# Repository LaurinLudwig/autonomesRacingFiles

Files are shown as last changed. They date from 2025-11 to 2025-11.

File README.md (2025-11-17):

# Projektübersicht & Nützliche Links

Dieses Repository enthält alle relevanten Unterlagen, Diagramme und Dateien rund um die Entwicklung unserer mobilen Roboterplattform und der zugehörigen Software-/Systemarchitektur.

## Inhalt des Repositories

- **CAD/**  
  enthält .Step und .3MF Dateien zum Drucken von Ersatzteilen

- **ChangedRosFiles/**  
  angepasste ROS-Dateien für unsere Plattform

- **Finanzplan_Antrag_Roboter_plattformen.xlsx**  
  Auflistung der verwendeten/bestellten Komponenten

- **KabelDiagramme.pdf / KabelDiagramme.pptx**  
  Übersicht der Verkabelung, Schnittstellen und elektrischen Verbindungen

- **SystemDiagramme.pdf / SystemDiagramme.pptx**  
  Schaubild der Komponenten

- **ReadmeAndUsefulLinks.md**  
  (Diese Datei) Kurze Einführung in das Repo und Sammlung relevanter Ressourcen.

## Useful Links

### Allgemein & Inspiration
- **Roboracer.ai**  
  https://roboracer.ai/

### Hardware / Jetson Setup
- **reComputer J4012 – JetPack Flash Guide**  
  https://wiki.seeedstudio.com/reComputer_J4012_Flash_Jetpack/

### Software / ROS 2
- **ROS 2 Humble Dokumentation**  
  https://docs.ros.org/en/humble/index.html

### F1TENTH / Driverless-Ökosystem
- **F1TENTH System Repository (humble-devel)**  
  *Hinweis: läuft nicht out-of-the-box; stattdessen Thomas Wiemanns Fork verwenden*  
  https://github.com/f1tenth/f1tenth_system/tree/humble-devel

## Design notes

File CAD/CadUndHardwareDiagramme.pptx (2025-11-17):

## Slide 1

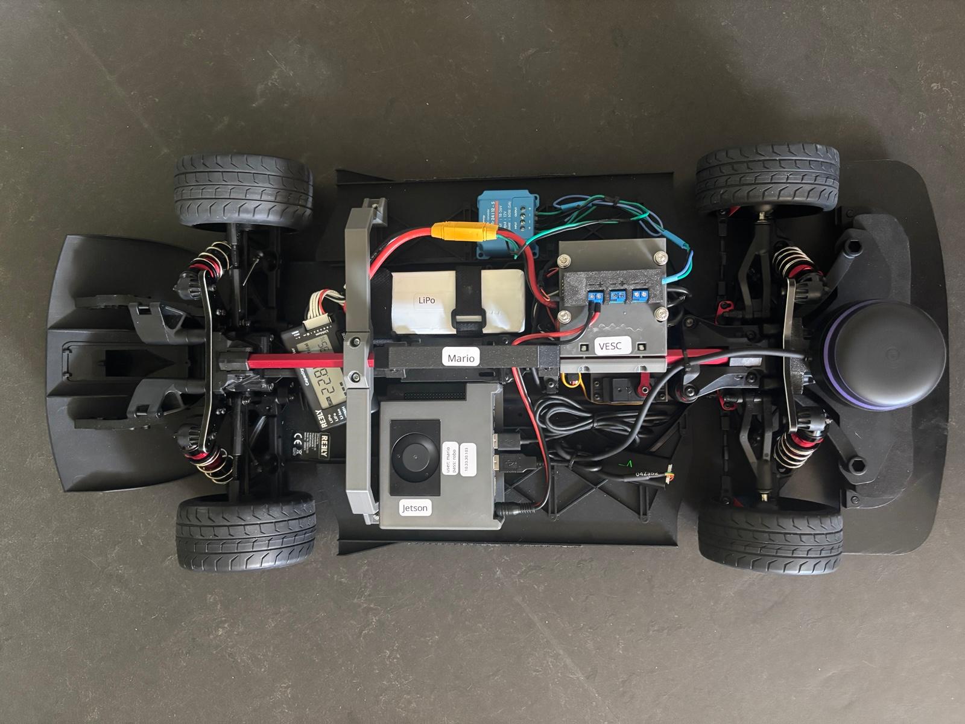
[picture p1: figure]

powerDistributionCover
(Lochrasterplatte, Terminals, 90 Grad Header Pins)

Handle + 2x HandleClamp
(4x M3, 4x M3 self locking Nut)

VescMount +
VescMountClamp
(4x M5, 4x M3,
4x M3 self locking Nut)

Enforcer Bracket +
EnforderBracketClamp
(4x M3, 4x M3 self locking Nut)

RPLidarMount
(2x M5, 4x M3)

JetsonCase +
JetsonCaseBottom
(4x M3)

ServoMount
(2x M4, 4x M3)

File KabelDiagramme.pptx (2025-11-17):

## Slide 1

DC 24V

DCDC 5V

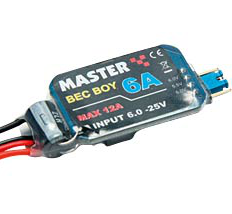
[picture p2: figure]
AKKU-BEC für RC-Empfänger, 6 A

DC 5V

Wifi Router

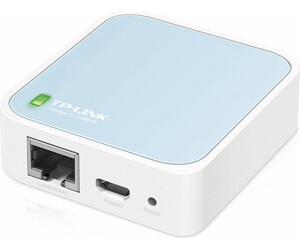
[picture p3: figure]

Ethernet

USB
DC 5V

optional DC 5V

RPLidar A3M1

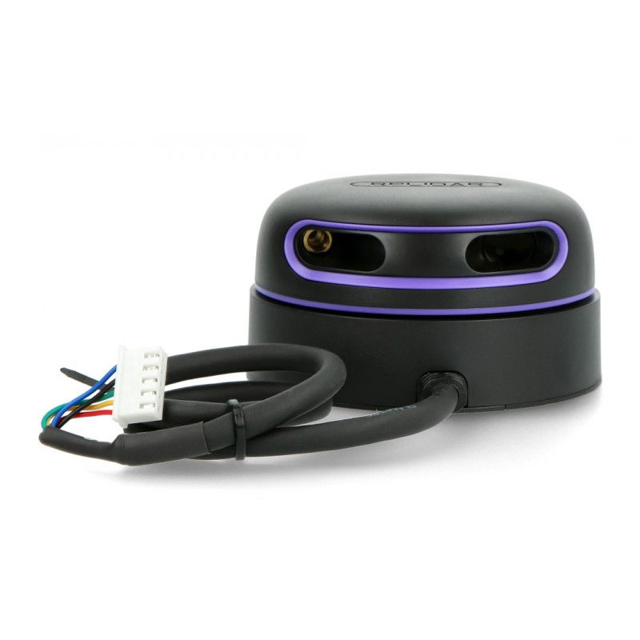
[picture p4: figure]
RPLidar A3M1 Laserscanner - 360 Grad - 25m

LiPo

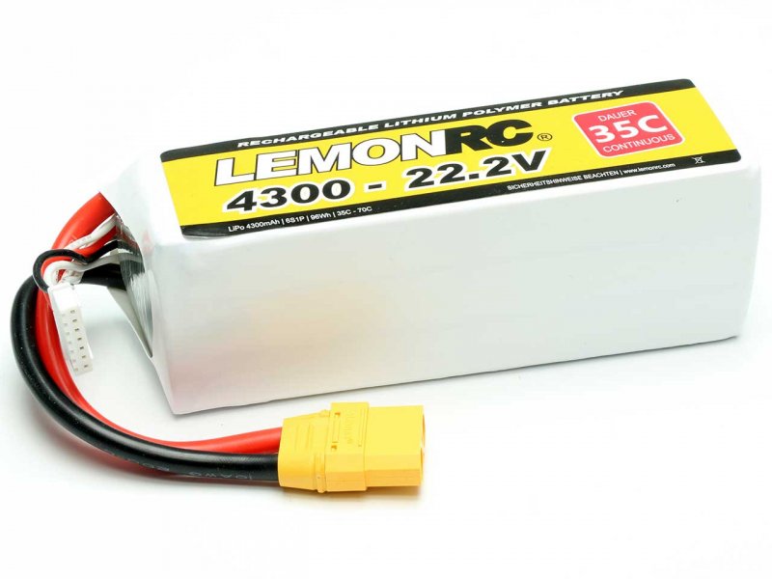
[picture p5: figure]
LiPo Akku LEMONRC 4300 - 22.2V (35C), 99,95 €

DC 24V

DC 24V

DCDC 12V

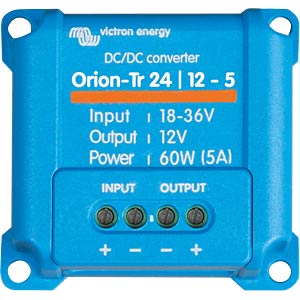
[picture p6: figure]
DC/DC Konverter, 12,7 V, 5 A

DC 12V

Nvidia Jetson Orin

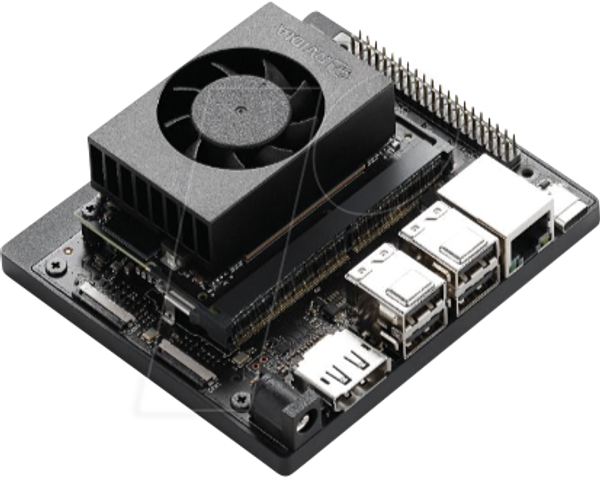
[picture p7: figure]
NVIDIA NVIDIA Jetson Orin Nano Super Dev. Kit, 67 TOPS, 8 GB DDR5 | Bundles / Sets / Kits günstig kaufen | reichelt elektronik

USB-UART
(Motor und Servo)

VESC 6

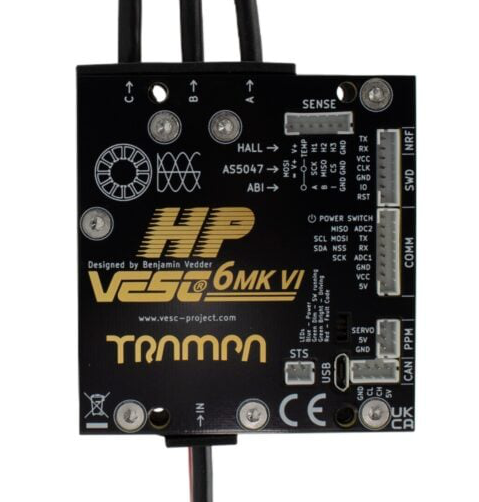
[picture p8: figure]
VESC 6 Mk6 HP - Trampa - The world leading brand of Electric Mountainboards

USB-UART
(Lidardaten)

Balancing Stecker
(Spannungsanzeige/
Unterspannungsschutz)

DC 24V

LiPo Checker

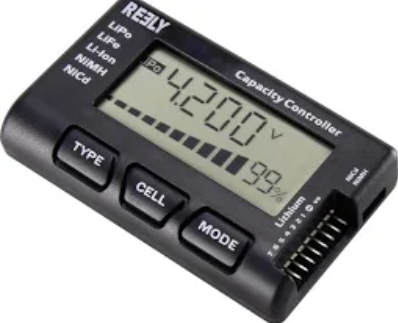
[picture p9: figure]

PWM-Output

Servo Motor

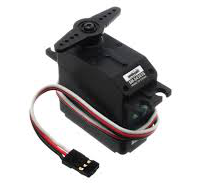
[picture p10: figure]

BLDC-Motor

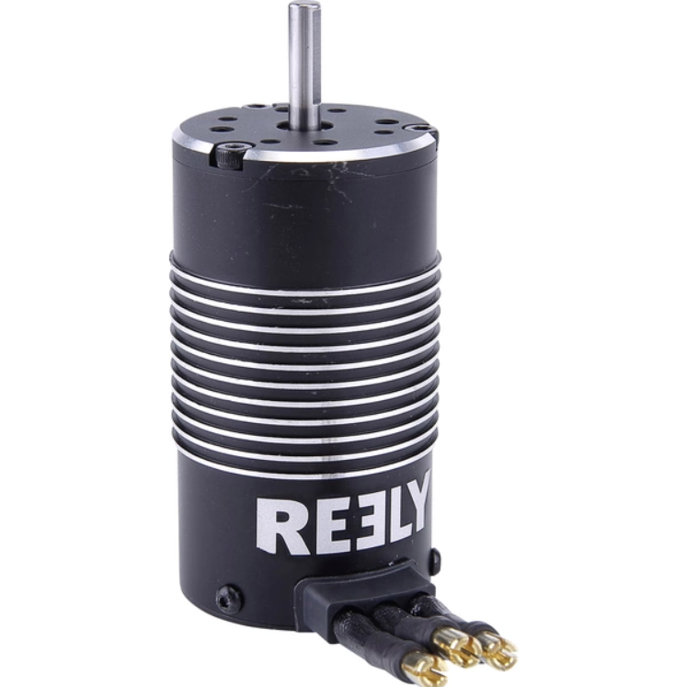
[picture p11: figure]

3 Motorphasen

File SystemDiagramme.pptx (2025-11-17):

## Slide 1


DCDC-Wandler
(24V-12V, 24V-5V)

Spannungsverteiler (12V, 5V)

Motorcontroller (VESC 6)

LiPo
(6S 4300mAH)

Motor
(BLDC 2000kV 3800W)

LiPo-Checker

Lidar (RPLidar A3M1)

Computer
(Jetson Orin NX,
8x 2 GHz, 16 GB DDR5)

Lenkmotor
(Standard Servo)

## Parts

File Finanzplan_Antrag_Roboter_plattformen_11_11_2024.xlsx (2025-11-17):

vorläufiger Finanzplan Antrag: Testplattformen für Autonomes Fahren
Stück | Artikel | Information | Preis | Gesamt | Link |  | Preis Gesamt für eine beginner und eine fortgeschrittene Plattform
 |  |  |  |  |  |  | 6750€ | (Alle Preise mit Steuern für End-User)
2 | NVIDIA Jetson Orin NX Bundle |  | 705 € | 1410 | https://www.reichelt.com/ch/de/shop/produkt/nvidia_jetson_orin_nx_bundle_8x_2_ghz_16_gb_ddr5-377868
2 | TIM361-2134101 | Preis auf Anfrage | 1550 € | 3100 | https://www.sick.com/de/de/produkte/lidar-und-radarsensoren/lidar-sensoren/tim/tim361-2134101/p/p369447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
 |  |  |  |  |  |  | Preis Gesamt für beantragte Summe für jeweils zwei Plattformen
2 | ODrive S1 and M8325s |  | 329 € | 658 | https://odriverobotics.com/shop/s1-and-m8325s-start-kit |  | 13500
2 | 1/7 RC Wheels |  | 40 € | 80 | https://www.conrad.de/de/p/reely-re-7867935-ersatzteil-komplettraeder-hinten-2622645.html
6 | Harness Build Kit For ODrive S1 |  | 9 € | 54 | https://odriverobotics.com/shop/harness-build-kit-for-odrive-s1
2 | Standard Servo |  | 25 € | 50 | https://www.reichelt.com/it/de/shop/produkt/standardservo_13_kg_digital_metallgetriebe-280644
1 | Servo Tester |  | 10 € | 10 | https://www.reichelt.com/it/de/shop/produkt/servotester_fuer_3_servos_ccpm_mini-119122
 |  |  |  | 0
2 | DYNAMIXEL AX-12A Servomotor | Alternative für Standard Servo, Comm. Over Uart | 60 € | 120 | https://www.reichelt.com/it/de/shop/produkt/servomotor_robotik_9_0_-_12_v_dc-249909
1 | 1/7 RC Auto Plattform |  | 350 € | 350 | https://www.conrad.de/de/p/reely-urban-green-brushless-1-7-rc-modellauto-elektro-strassenmodell-allradantrieb-4wd-rtr-2-4-ghz-mit-lichteffekt-t-2586837.html
1 | ODrive S1 | Foc BLDC Motor Driver for 1/7 Car | 149 € | 149 | https://eu.odriverobotics.com/shop/odrive-s1
1 | Odrive S1 Case |  | 19 € | 19 | https://eu.odriverobotics.com/shop/enclosure-for-odrive-s1
1 | Mono IMX219-160 |  | 25 € | 25 | https://www.conrad.de/de/p/waveshare-imx219-160-ir-kamera-8mp-160-fov-infrarot-ai-gesichtserkennung-jetson-nano-xavier-nx-906009355.html
1 | Stereo IMX219-83 |  | 45 € | 45 | https://www.conrad.de/de/p/stereo-kamera-modul-imx219-83-8-megapixel-838242168.html
1 | Akku Ladegerät |  | 45 € | 45 | https://www.reichelt.com/it/de/shop/produkt/ladegeraet_fuer_akkupacks_fuer_1-6s_max_6_a-271070
2 | 24v Lipo Akku |  | 85 € | 170 | https://www.reichelt.com/it/de/shop/produkt/lipo_akku_lemonrc_3300_-_22_2v_35c_-385712
1 | 5v Regler mit Abschaltung |  | 9.50 € | 9.5 | https://www.conrad.de/de/p/hobbywing-bec-3a-ubec-bec-spannungsregler-5-5-26-v-2108347.html
1 | Step up/down wandler für jetson |  | 50 € | 50
1 | Verschiedenes |  | 405.5 € | 405.5
Update 11.11.2024
Anz | Artikel | ohne MwSt | mit | ges | Link
4 | NVIDIA Jetson Orin NX Bundle |  | 996.8 | 3987.2 | JET ORIN 4012: NVIDIA Jetson Orin NX Bundle, 8x 2 GHz, 16 GB DDR5 bei reichelt kaufen (https://www.reichelt.com/de/de/shop/produkt/nvidia_jetson_orin_nx_bundle_8x_2_ghz_16_gb_ddr5-377868) | gibt’s nur da
4 | RPLIDAR A3M1 360° LiDAR (25m) |  | 706.6 | 2826.4 | https://www.reichelt.de/rplidar-a3m1-360-lidar-25m--rplidar-a3m1-p287745.html?&trstct=vrt_pdn&nbc=1 | Angebot | Alternative | Anz | Artikel | ohne | mit | ges
5 | VESC 6MkVI | 195 | 232.05 | 1160.25 | The Amazing TRAMPA VESC 6 MkVI gives Maximum power! (https://trampaboards.com/vesc-6-mkvi--trampa-gives-you-maximum-power-p-34848.html) | gibt’s nur da |  | 4 | ODrive S1 | 149 | 177.31 | 709.24 | ODrive S1 — ODrive Europe (https://eu.odriverobotics.com/shop/odrive-s1)
8 | vesc 6 ppm cable for servo | 2.5 | 2.975 | 23.8 | https://trampaboards.com/maytech-to-vesc-150mm-ppm-extension-cable--silicon-cable-24-awg-blackredwhite-p-24329.html |  |  | 4 | Odrive S1 Case | 19 | 22.61 | 90.44 | Enclosure for ODrive S1 — ODrive Europe (https://eu.odriverobotics.com/shop/enclosure-for-odrive-s1)
4 | Raspberry Pi - Kamera, 5MP, 160° |  | 12.08 | 48.32 | RPI WWCAM: Raspberry Pi - Kamera, 5MP, 160° bei reichelt elektronik (https://www.reichelt.de/raspberry-pi-kamera-5mp-160--rpi-wwcam-p148944.html?PROVID=2788&gad_source=1) |  |  | 4 | Odrive USB-CAN Adapter | 39 | 46.41 | 185.64 | USB-CAN Adapter — ODrive Europe (https://eu.odriverobotics.com/shop/usb-can-adapter)
4 | 1/7 RC Auto Plattform |  | 335.29 € | 1341.16 | Reely Urban Green Brushless 1:7 RC Modellauto Elektro Straßenmodell Allradantrieb (4WD) RtR 2,4 GHz mit Lichteffekt, T kaufen (https://www.conrad.de/de/p/reely-urban-green-brushless-1-7-rc-modellauto-elektro-strassenmodell-allradantrieb-4wd-rtr-2-4-ghz-mit-lichteffekt-t-2586837.html) | Angebot
4 | Akku Ladegerät IMAX B6AC V2 |  | 71.95 | 287.8 | IMAX B6AC V2: Ladegerät für Akkupacks, für 1 - 15 Zellen, max. 6 A, USB bei reichelt elektronik (https://www.reichelt.de/ladegeraet-fuer-akkupacks-fuer-1-15-zellen-max-6-a-usb-imax-b6ac-v2-p182805.html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)
8 | 24v 6s 4300mah Lipo Akku |  | 99.95 | 799.6 | https://www.conrad.de/de/p/lemonrc-modellbau-akkupack-lipo-22-2-v-4300-mah-zellen-zahl-6-35-c-softcase-xt90-2867021.html | Screenshots
4 | 5v Regler mit Abschaltung |  | 29.4 | 117.6 | MASTER C6354: AKKU-BEC für RC-Empfänger, 6 A bei reichelt elektronik (https://www.reichelt.de/akku-bec-fuer-rc-empfaenger-6-a-master-c6354-p265511.html?search=bec)
4 | 24-12V wandler VE TR 24/12-5 |  | 15.47 | 61.88 | VE TR 24 - 12-5: DC - DC Konverter, 12,7 V, 5 A bei reichelt elektronik (https://www.reichelt.de/dc-dc-konverter-12-7-v-5-a-ve-tr-24-12-5-p300230.html?PROVID=2788&gad_source=1)
4 | Relais GRV RELAY SPDT30 |  | 11.2 | 44.8 | GRV RELAY SPDT30: Arduino - Relais SPDT, 30 A, SLA-05VDC-SL-C bei reichelt elektronik (https://www.reichelt.de/arduino-relais-spdt-30-a-sla-05vdc-sl-c-grv-relay-spdt30-p243033.html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)
2 | Lipo Tasche EXTRON X3363 |  | 34.2 | 68.4 | EXTRON X3363: Lithium Tresor, inkl. Fireballs 3x 1L bei reichelt elektronik (https://www.reichelt.de/lithium-tresor-inkl-fireballs-3x-1l-extron-x3363-p253651.html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)
1 | 2,5mm2 Kabel |  | 15 | 15 | GOOBAY 15099: Lautsprecherkabel 2x2,5mm² , 10 m rot/schwarz CU bei reichelt kaufen (https://www.reichelt.com/ch/de/shop/produkt/lautsprecherkabel_2x2_5mm_10_m_rot_schwarz_cu-364183)
4 | LiPo-Checker |  | 17.99 | 71.96 | https://www.conrad.de/de/p/reely-lipo-checker-geeignet-fuer-batterie-zellen-2-7-1-st-re-6546762-2182254.html
 |  |  | Summe | 10854.17

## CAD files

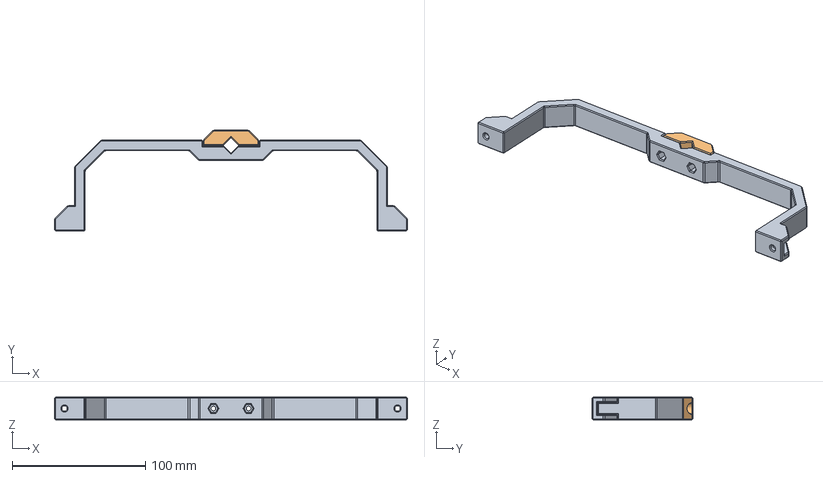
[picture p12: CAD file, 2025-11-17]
CAD/EnforcingBracket/SideplateEnforcingBracket.step
265.0 x 75.7 x 17.0 mm

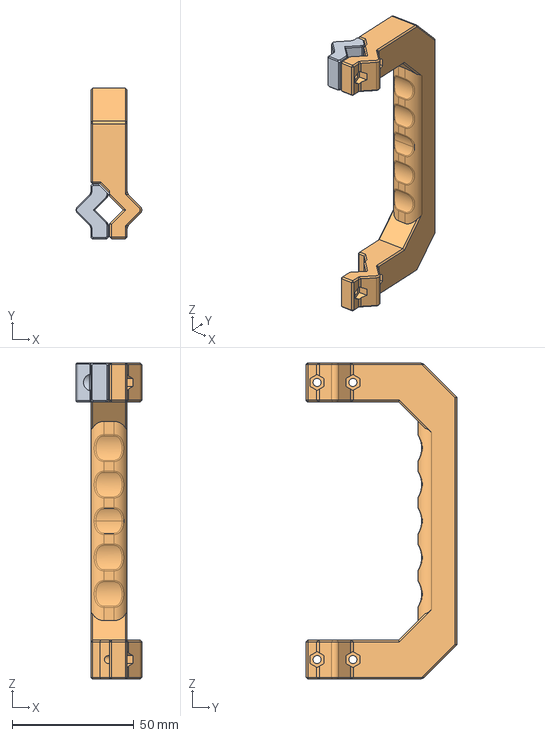
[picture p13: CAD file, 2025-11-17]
CAD/Handle/handle.step
27.0 x 62.0 x 130.0 mm

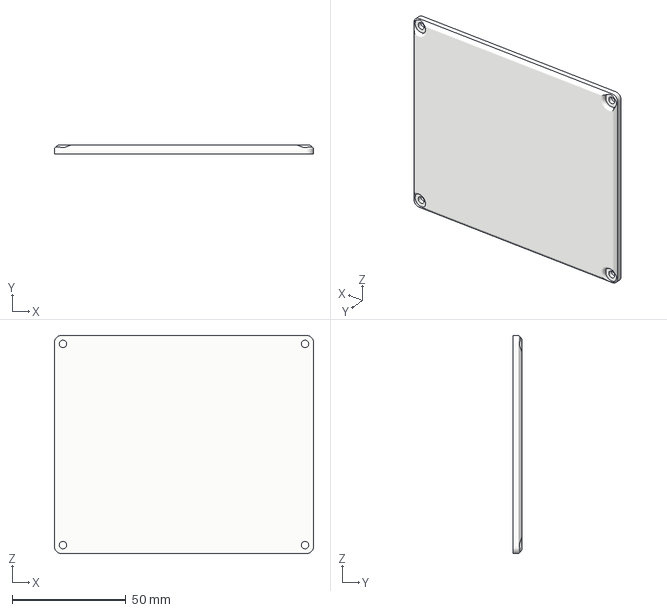
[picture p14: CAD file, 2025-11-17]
CAD/JetsonCase/case_m3_self_tapping/Lid.3mf
114.0 x 4.00 x 96.0 mm

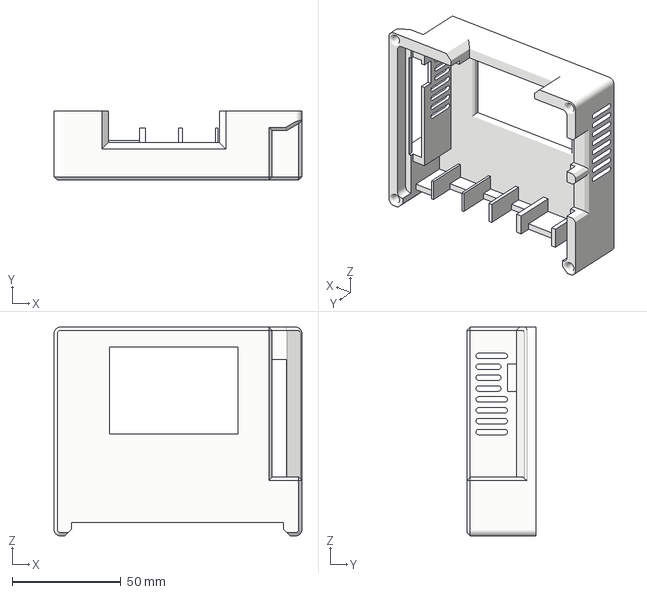
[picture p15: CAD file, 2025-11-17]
CAD/JetsonCase/case_with_m3_inserts/JetsonCaseM3Inserts.3mf
114.0 x 31.8 x 96.0 mm

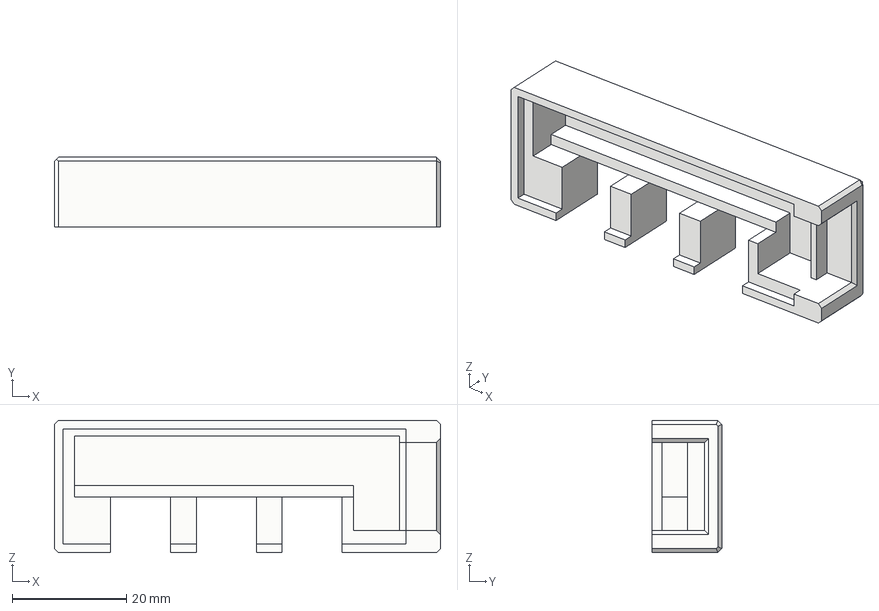
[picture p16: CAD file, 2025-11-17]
CAD/powerDistributionCover/PowerDistriCover.step
67.5 x 12.2 x 23.1 mm

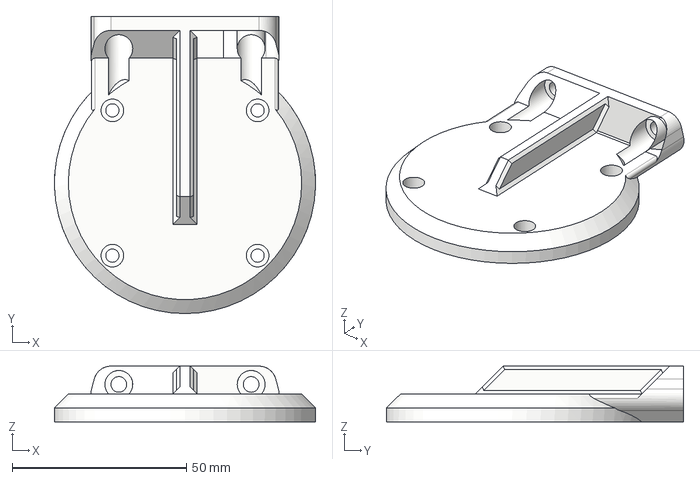
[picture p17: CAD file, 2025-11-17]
CAD/RPLidarMount/mounting_position_high/RPLidar_Mount_high.step
75.0 x 85.4 x 16.0 mm

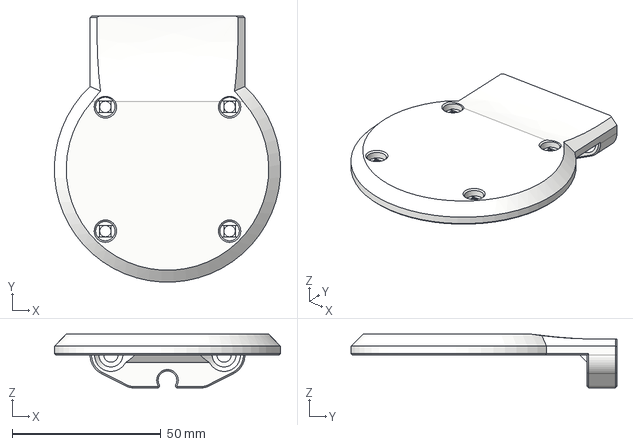
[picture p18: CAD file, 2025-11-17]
CAD/RPLidarMount/mounting_position_low/RPLidar_Mount_low.step
75.9 x 89.3 x 18.0 mm

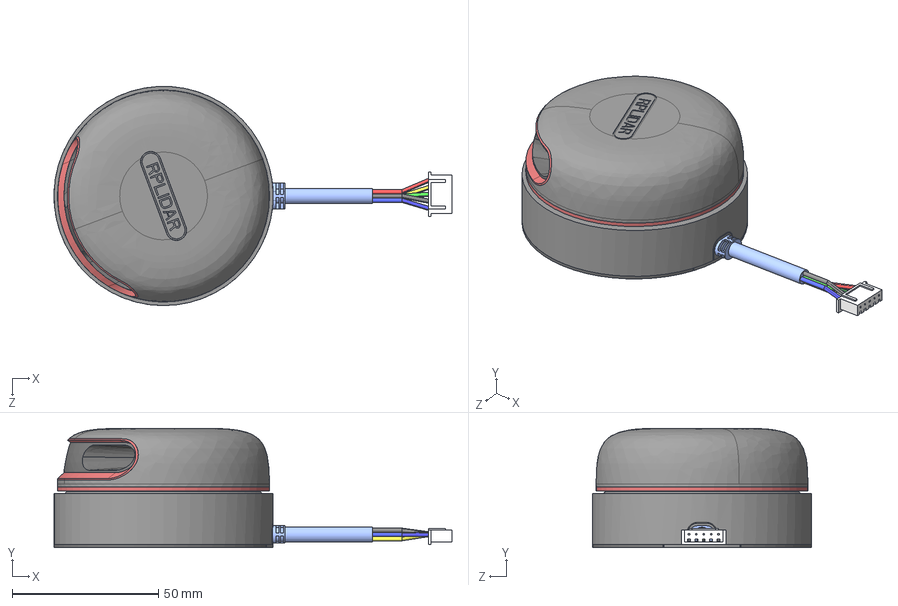
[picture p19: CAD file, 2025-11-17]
CAD/RPLidarMount/rplidar-a2m4-r1.step
136.2 x 40.8 x 75.0 mm
µ×¸Ç
4pinÏßÀÂ
½ÓÏß¶Ë¸Ç
6p ²åÍ·
Áã¼þ4^Íâ½ÓÏßÕ ûÌå
5pin 2.54²åÍ·
Áã¼þ1^Íâ½ÓÏßÕ ûÌå
±àÂë³ÝÍâ¿Ç
Ðý×ªÆ½Ì¨
LENS_1.6
KEY_1.6
BAT_COVER_19
·â¸Ç
¼¤¹â·¢ÉäÍ·
¾µÍ·

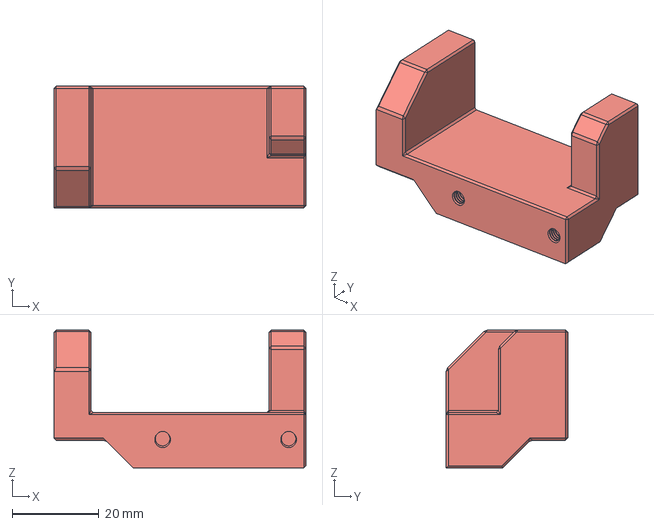
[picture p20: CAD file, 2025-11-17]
CAD/ServoMount/ServoMount.step
58.0 x 28.0 x 31.8 mm

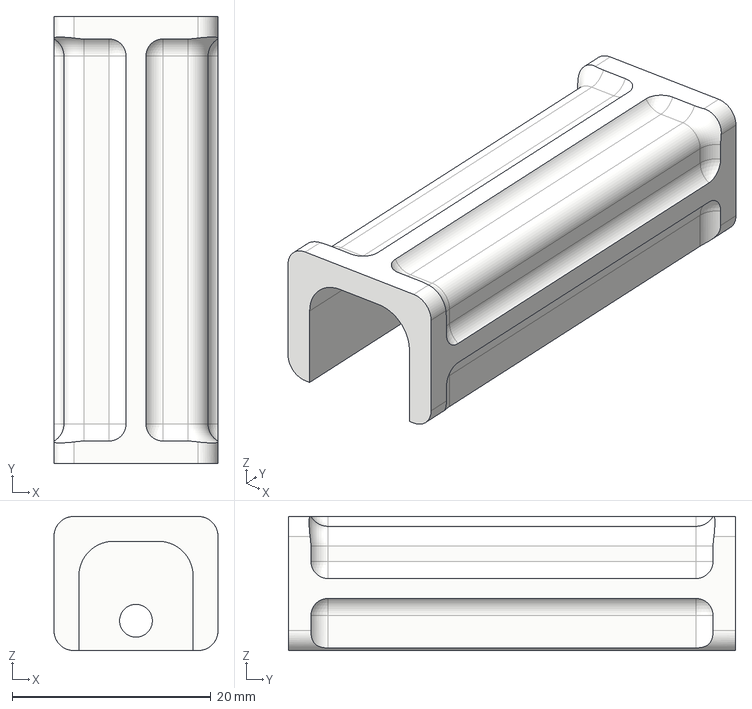
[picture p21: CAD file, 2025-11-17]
CAD/SprocketCover/SprocketCover.step
16.5 x 45.0 x 13.5 mm

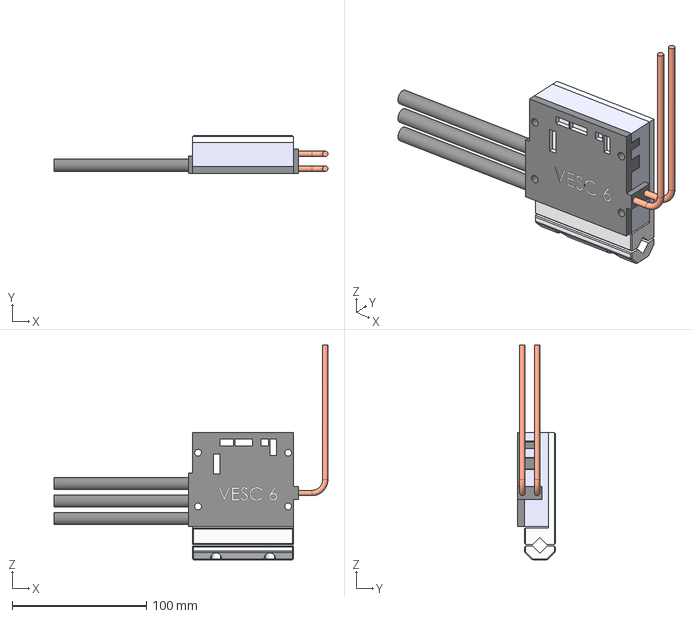
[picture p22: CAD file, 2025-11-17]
CAD/VescMount/VescMount.step
203.8 x 28.0 x 159.7 mm
VESC6HeatSink
VESC6Top

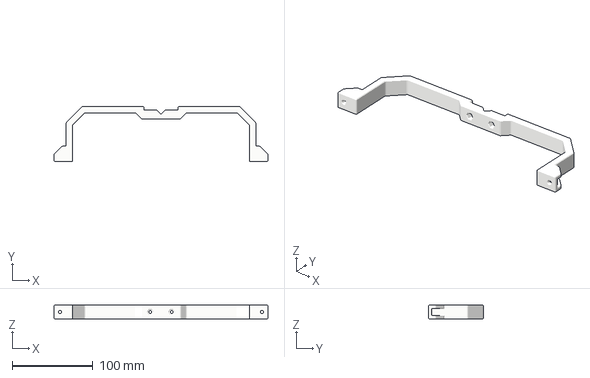
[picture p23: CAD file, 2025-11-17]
CAD/EnforcingBracket/EnforcingBracket.3mf
265.0 x 68.2 x 17.0 mm

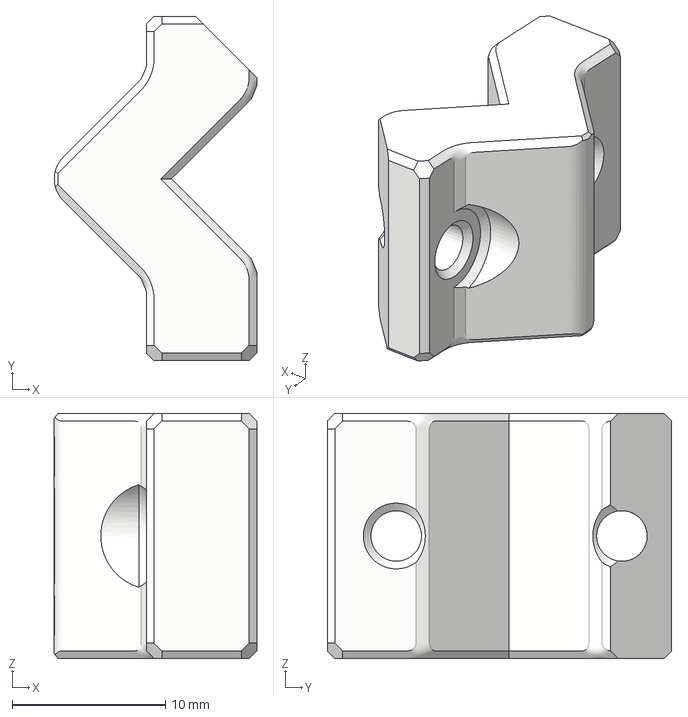
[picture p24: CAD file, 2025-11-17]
CAD/Handle/handle_clamp.3mf
13.2 x 22.5 x 16.0 mm

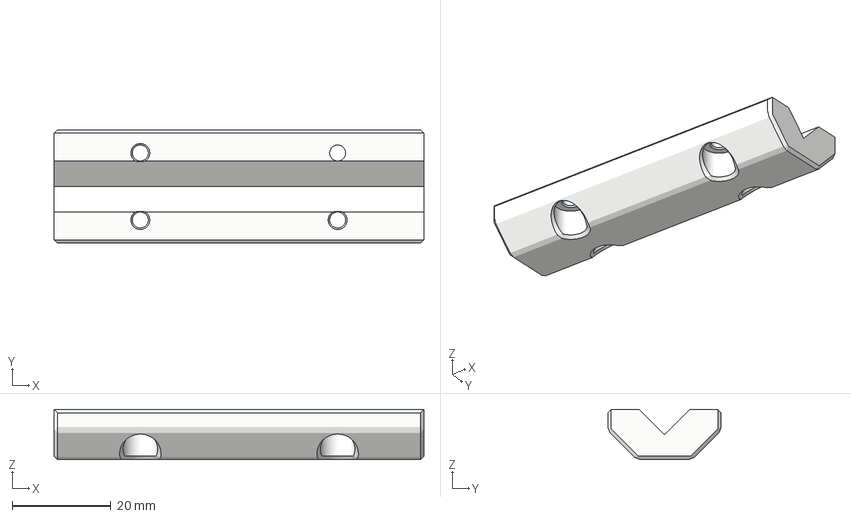
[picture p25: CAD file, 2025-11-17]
CAD/VescMount/VescMountClamp.3mf
75.0 x 23.0 x 10.2 mm

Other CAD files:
CAD/JetsonCase/case_m3_self_tapping/Case.3mf
CAD/JetsonCase/case_with_m3_inserts/JetsonCaseBottomM3Inserts.3mf
CAD/powerDistributionCover/Cover.3mf
CAD/EnforcingBracket/EnforcingBracketClamp.3mf
CAD/Handle/handle.3mf
CAD/RPLidarMount/mounting_position_high/RPLidar_Mount_high.3mf
CAD/RPLidarMount/mounting_position_low/RPLidar_Mount_low.3mf
CAD/ServoMount/ServoMount.3mf
CAD/SprocketCover/SprocketCover.3mf
CAD/VescMount/VescMount.3mf

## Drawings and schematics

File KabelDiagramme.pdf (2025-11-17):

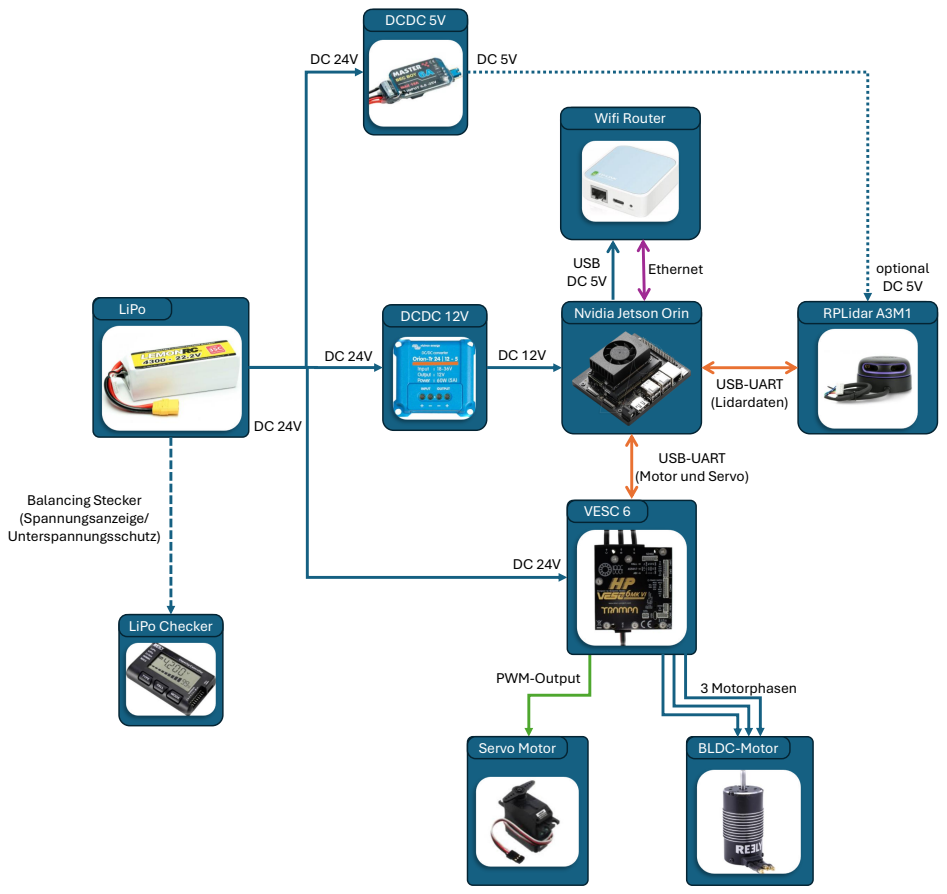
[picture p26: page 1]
VESC 6; Servo Motor; BLDC-Motor; LiPo; DCDC 12V; DCDC 5V; RPLidar A3M1; LiPo Checker; USB-UART (Lidardaten); PWM-Output; 3 Motorphasen; Balancing Stecker (Spannungsanzeige/ Unterspannungsschutz); optional DC 5V; Wifi Router

Ethernet USB
Nvidia Jetson Orin

USB-UART
(Motor und Servo)

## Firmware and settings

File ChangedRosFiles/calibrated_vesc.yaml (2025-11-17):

# calibrated_vesc.yaml
# These parameters have only been calibrated for the specific vehicle and can differ from vehicle to vehicle.
# Take care when reusing these parameters on a different vehicle.

/**:
  # general parameters shared by all vesc-related nodes
  ros__parameters:
    # erpm (electrical rpm) = speed_to_erpm_gain * speed (meters / second) + speed_to_erpm_offset
    speed_to_erpm_gain: 3700.0
    speed_to_erpm_offset: 0.0

    # servo value (0 to 1) =  steering_angle_to_servo_gain * steering angle (radians) + steering_angle_to_servo_offset
    steering_angle_to_servo_gain: -1.1
    steering_angle_to_servo_offset: 0.51

    port: /dev/sensors/vesc
    duty_cycle_min: 0.0
    duty_cycle_max: 0.0
    current_min: 0.0
    current_max: 100.0
    brake_min: -20000.0
    brake_max: 200000.0
    speed_min: -23250.0
    speed_max: 23250.0
    position_min: 0.0
    position_max: 0.0
    servo_min: 0.1
    servo_max: 0.9
# No longer needed, all parameters are shared
# ackermann_to_vesc_node:
#   ros__parameters:

vesc_to_odom_node:
  ros__parameters:
    odom_frame: odom
    base_frame: base_link
    # publish odom to base link tf
    publish_tf: true
    use_servo_cmd_to_calc_angular_velocity: true
    # car wheelbase is about 25cm
    wheelbase: .42

# No longer needed, all parameters are shared
# vesc_driver:
#   ros__parameters:

throttle_interpolator:
  ros__parameters:
    rpm_input_topic: commands/motor/unsmoothed_speed
    rpm_output_topic: commands/motor/speed
    servo_input_topic: commands/servo/unsmoothed_position
    servo_output_topic: commands/servo/position

    # servo smoother - limits acceleration and smooths anything above limit
    max_acceleration: 2.5 # meters/second^2
    throttle_smoother_rate: 75.0 # messages/sec
    # servo smoother - limits rotation speed and smooths anything above limit
    max_servo_speed: 3.2 # radians/second
    servo_smoother_rate: 75.0 # messages/sec
